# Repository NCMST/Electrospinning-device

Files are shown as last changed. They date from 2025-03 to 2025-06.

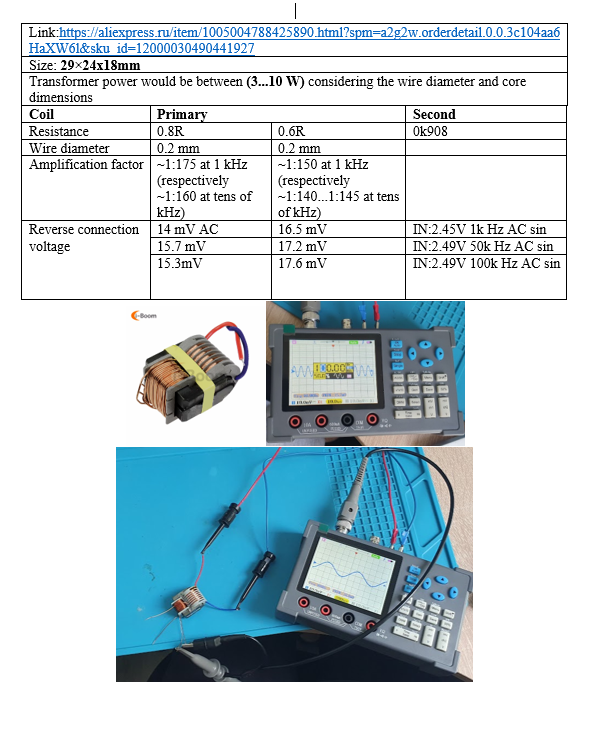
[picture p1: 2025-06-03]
Images/Transformer value.png

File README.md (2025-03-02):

<h2>Contents</h2>

<ul>
  <li><a href="#features">Features</a></li>
  <li><a href="#hardware-setup">Hardware Setup</a></li>
  <li><a href="#software-board-code">Software Board Code</a></li>
  <li><a href="#usage">Usage</a></li>
  <li><a href="#contributing">Contributing</a></li>
  <li><a href="#license">License</a></li>
</ul>

<h1>Electrospinning Device based on ATMEGA2560</h1>

<p>This repository contains the source code, hardware schematics, and documentation for a device designed to facilitate the electrospinning process using the ATMEGA2560 microcontroller (Arduino Mega).</p>

<h2 id="features">Features</h2>

<p>The device provides the following features:</p>
<ul>
  <li>Control and monitoring with BME280 sensor of temperature, pressure, humidity. And adjustable flow rate.</li>
  <li>FreeRTOS based task scheduler for easier and more efficient task management.</li>
  <li>High voltage source for electrospinning process.</li>
  <li>LCD display for monitoring.</li>
  <li>Motor for controlling the flow of the syringe. using driver TB6600.</li>
  <li>Encoder for user interaction.</li>
</ul>

<h2 id="hardware-setup">Hardware Setup</h2>

<table>
  <tr>
    <th>
      <p>The hardware setup consists of the following components:</p>
    </th>
  <tr>
    <td>
      <ul>
        <li><b>The high voltage power supply</b> generates the high voltage needed for the electrospinning process. It provides a stable and adjustable voltage source to create the electrostatic field required to draw the polymer solution into nanofibers.</li>
        <li><b>Varistor and Transformer</b> convert the high voltage to the voltage required for electrospinning.</li>
        <li><b>Multiplier/Rectifier</b> converts the voltage to the voltage required for the motor.</li>
      </ul>
    </td>
  </tr>
  <tr>
    <td>
      <h3>Comand Board</h3>
        <ul>
        <li><b>MCU</b> ATMEGA2560 (Mega 2560)</li>
        <li><b>Encoder</b> For seting the flow rate, starting and stopping the motor, and opening screen with sensor values.</li>
        <li><b>LCD Display</b> Show sensor values.</li>
        <li><b>TB6600</b> Stepper motor driver.</li>
        <li><b>Motor</b> Stepper motor for controlling the flow of the syringe.</li>
        <li><b>BME280</b> Sensor for monitoring temperature, pressure, and humidity.</li>
        <li><b>Power Supply</b> MCU power supply.</li>
      </ul>
    </td>
  </tr>
</table>
<ul>
  <li>See more about <a href="/Hardware/README.md">hardware Setup</a></li>
</ul>

<h2 id="software-board-code">Software Board Code</h2>
<ul>
  <li>See more about <a href="/Software/Source_code">software board code.</a></li>
  <!-- Builded file is ... -->
  <li>Get hex, elf files: <a href="/Software/Source_code/build/">software bulded code.</a></li>
</ul>

<h2>Usage</h2>

<p>To use the electrospinning device:</p>
<ol>
  <li>Connect the high voltage source to 220V.</li>
  <li>Connect the Arduino Mega to the components and upload the provided source code.</li>
  <li>Use the LCD screen with encoder to control and monitor the electrospinning process.</li>
  <li>Adjust the settings as needed and start the electrospinning process.</li>
  <li>Monitor the output and make adjustments as necessary.</li>
</ol>

<h2>Contributing</h2>
<p>Contributions to this project are welcome. Please fork the repository, make your changes, and submit a pull request.</p>

<h2>License</h2>
<p>This project is licensed under the <a href="LICENSE">MIT License</a>.</p>

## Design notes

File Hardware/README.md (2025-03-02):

# Electrospinning Device based on Arduino Mega

## High voltage result and schematics

### Reult

<p> The result of the electrospinning process is accesible on link below. </p>
<a href="https://docs.google.com/spreadsheets/d/1FEkuDaI_2rEFF1M06S9z06Yd7cQ-smT4pYeCvJsIN_U/edit?usp=sharing">Value on testing process</a>

### Schematics

## Hardware Connection

<h3>Display LCD I2C 16x2</h3>
<table style="border: none;">
  <tr>
    <th>Arduino Pins</th>
    <th>LCD Pin</th>
  </tr>
  <tr>
    <td>20</td>
    <td>21</td>
  </tr>
  <tr>
    <td>SCL</td>
    <td>SDA</td>
  </tr>
</table>

<h3>Motor</h3>
<table style="border: none;">
  <tr>
    <th>Arduino Pins</th>
    <th>Driver TB6600</th>
    <th>Motor Pin</th>
  </tr>
  <tr>
    <td>48</td>
    <td>ENA</td>
    <td>Enable Motor</td>
  </tr>
  <tr>
    <td>46</td>
    <td>DIR</td>
    <td>Direction Motor</td>
  </tr>
  <tr>
    <td>44</td>
    <td>PUL</td>
    <td>Pulse Motor</td>
  </tr>

  <h3>Encoder</h3>
  <table style="border: none;">
  <tr>
    <th>Arduino Pins</th>
    <th>Driver TB6600</th>
    <th>Encoder Pin</th>
  </tr>
  <tr>
    <td>26</td>
    <td>CLK</td>
    <td>Encoder Clock</td>
  </tr>
  <tr>
    <td>24</td>
    <td>DT</td>
    <td>Encoder Data transfer</td>
  </tr>
  <tr>
    <td>22</td>
    <td>SW</td>
    <td>Encoder Switch select</td>
  </tr>
  </table>

<h3>ADC</h3>
<table style="border: none;">
  <tr>
    <th>Arduino Pins</th>
    <th>ADC Pin</th>
  </tr>
  <tr>
    <td>A9</td>
    <td>ADC</td>
  </tr>
</table>

<h3>PWM</h3>
<table style="border: none;">
  <tr>
    <th>Arduino Pins</th>
    <th>PWM Pin</th>
  </tr>
  <tr>
    <td>9</td>
    <td>PWM</td>
  </tr>
</table>

<h3>Relay</h3>
<table style="border: none;">
  <tr>
    <th>Arduino Pins</th>
    <th>Relay Pin</th>
  </tr>
  <tr>
    <td>15</td>
    <td>Relay</td>
  </tr>
</table>

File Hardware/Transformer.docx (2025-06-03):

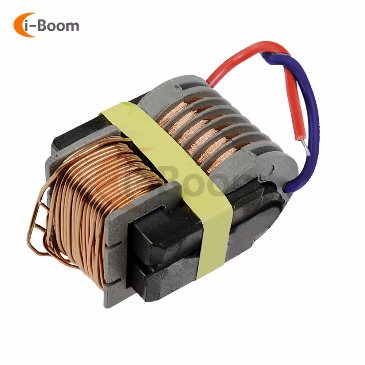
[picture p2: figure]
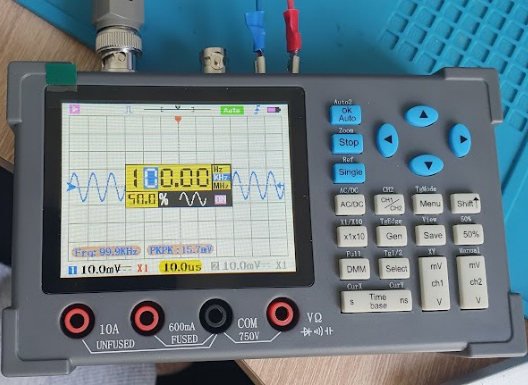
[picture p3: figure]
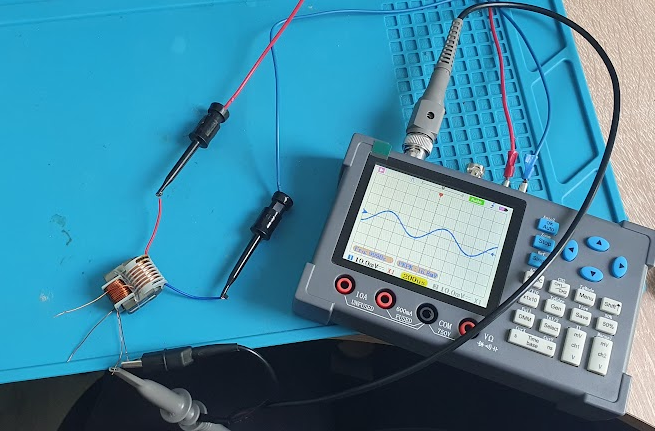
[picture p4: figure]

Link:https://aliexpress.ru/item/1005004788425890.html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

Size: 29×24x18mm

Transformer power would be between (3...10 W) considering the wire diameter and core dimensions
Coil | Primary | | Second
Resistance | 0.8R | 0.6R | 0k908
Wire diameter | 0.2 mm | 0.2 mm
Amplification factor | ~1:175 at 1 kHz (respectively ~1:160 at tens of kHz) | ~1:150 at 1 kHz (respectively ~1:140...1:145 at tens of kHz)
Reverse connection voltage | 14 mV AC | 16.5 mV | IN:2.45V 1k Hz AC sin
| 15.7 mV | 17.2 mV | IN:2.49V 50k Hz AC sin
| 15.3mV | 17.6 mV | IN:2.49V 100k Hz AC sin

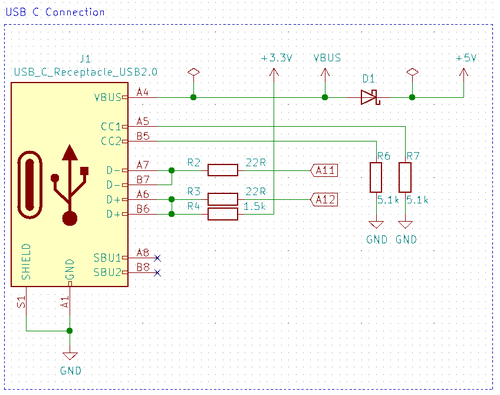
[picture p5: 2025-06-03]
Images/STM32 USB_Circuit_w._1.5_kOhm_pull-up.png

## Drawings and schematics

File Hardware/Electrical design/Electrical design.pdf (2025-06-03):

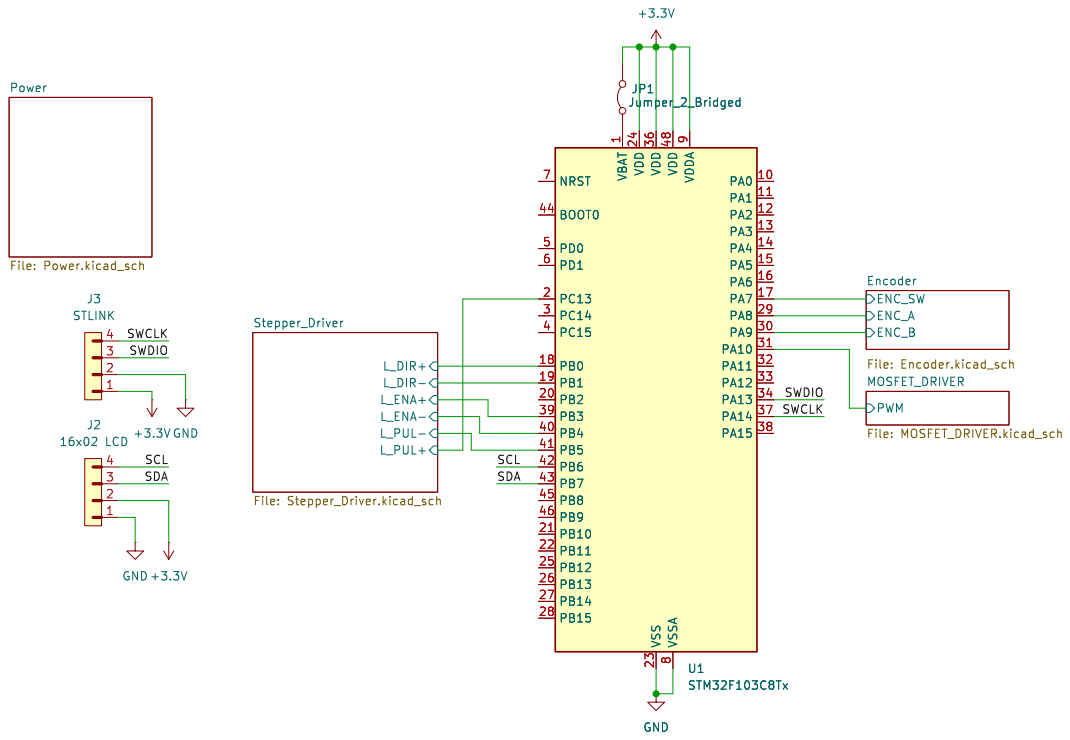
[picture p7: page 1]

File: MOSFET_DRIVER.kicad_sch Power File: Power.kicad_sch

1 VDD 24 VDD 36 VSS 23 VDD 48 VSSA

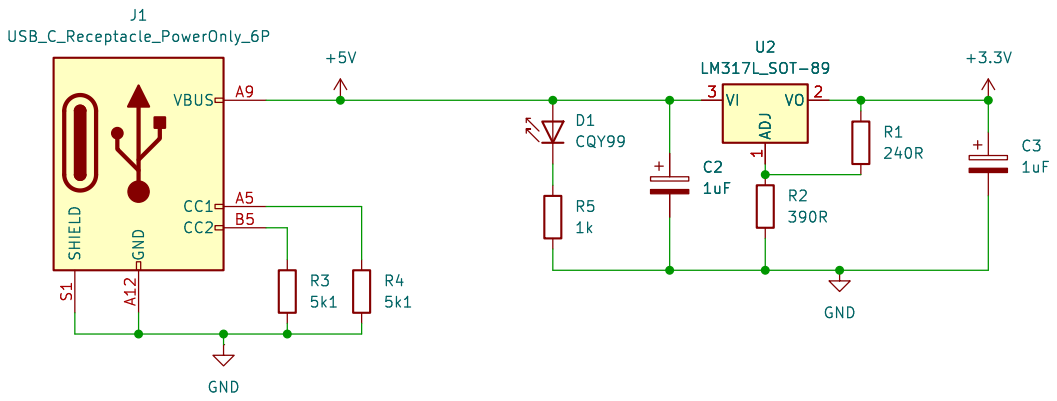
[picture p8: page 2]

Id: 2/5 Title: Power File: untitled.kicad_sch Sheet: /Power/R2

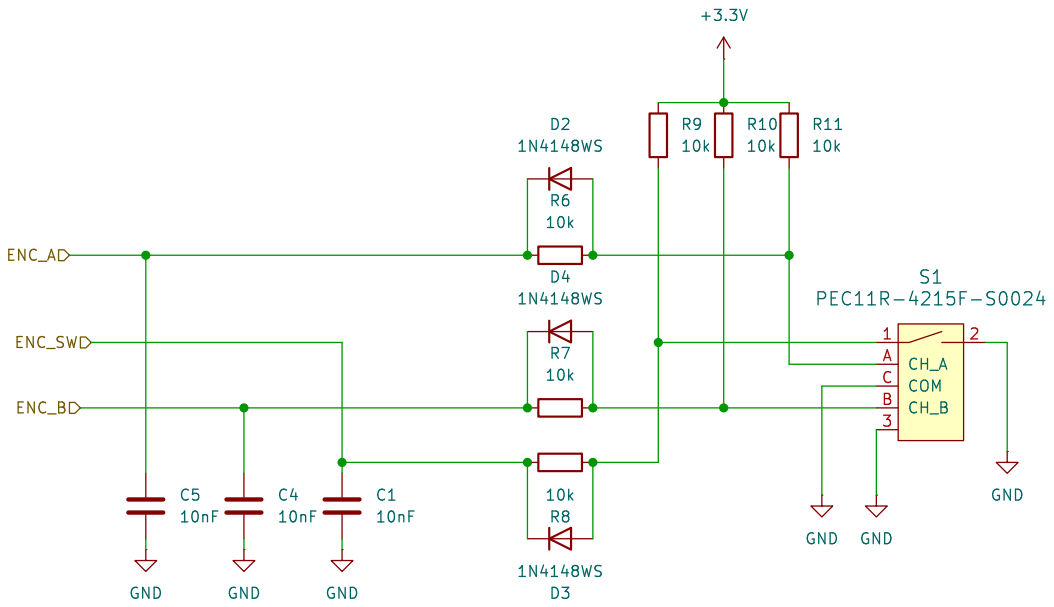
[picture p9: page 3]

Id: 3/5 Title: Power File: Encoder.kicad_sch Sheet: /Encoder/ GND

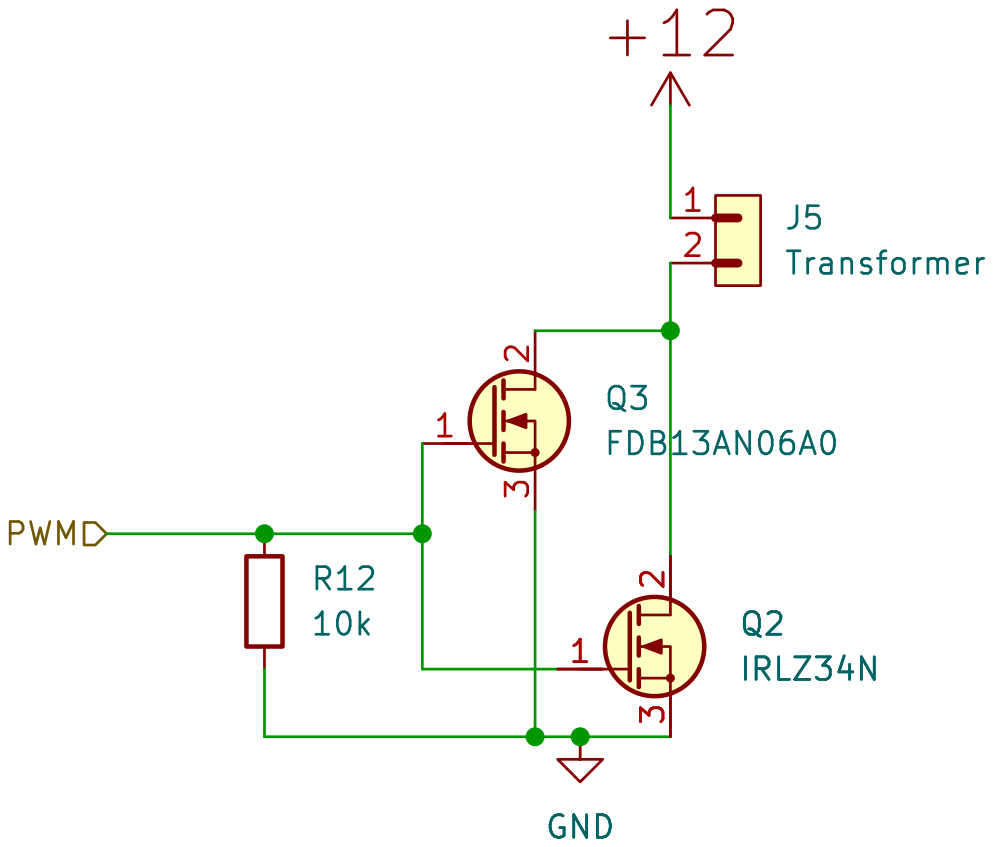
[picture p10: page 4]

Id: 4/5 Title: Power File: MOSFET_DRIVER.kicad_sch Sheet: /MOSFET_DRIVER/

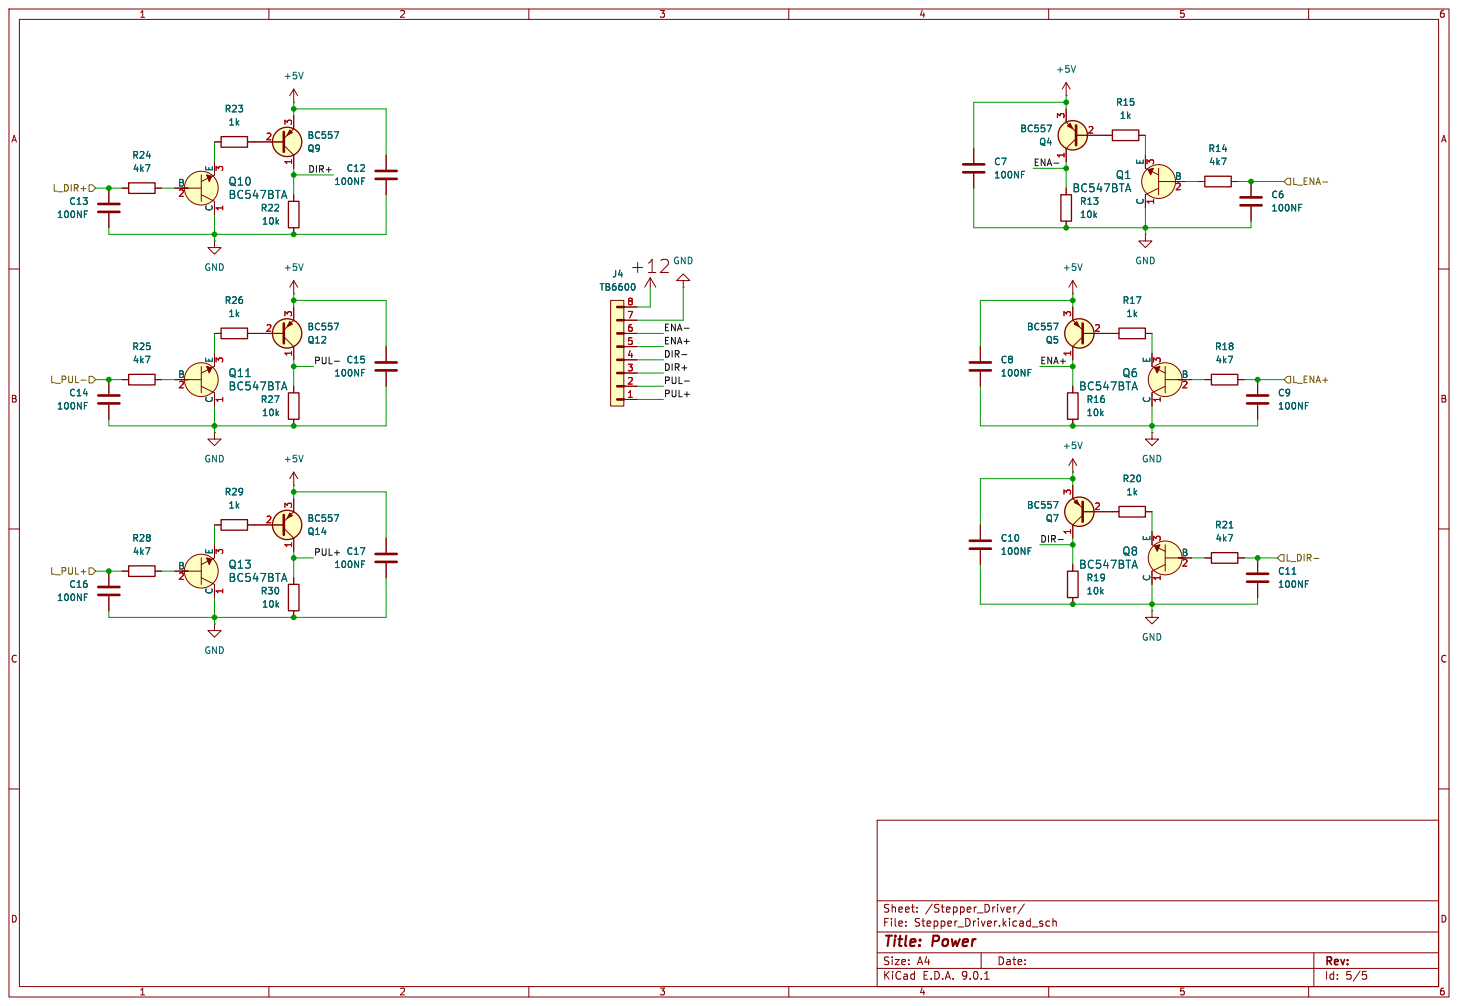
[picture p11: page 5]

Id: 5/5 Title: Power File: Stepper_Driver.kicad_sch Sheet: /Stepper_Driver/

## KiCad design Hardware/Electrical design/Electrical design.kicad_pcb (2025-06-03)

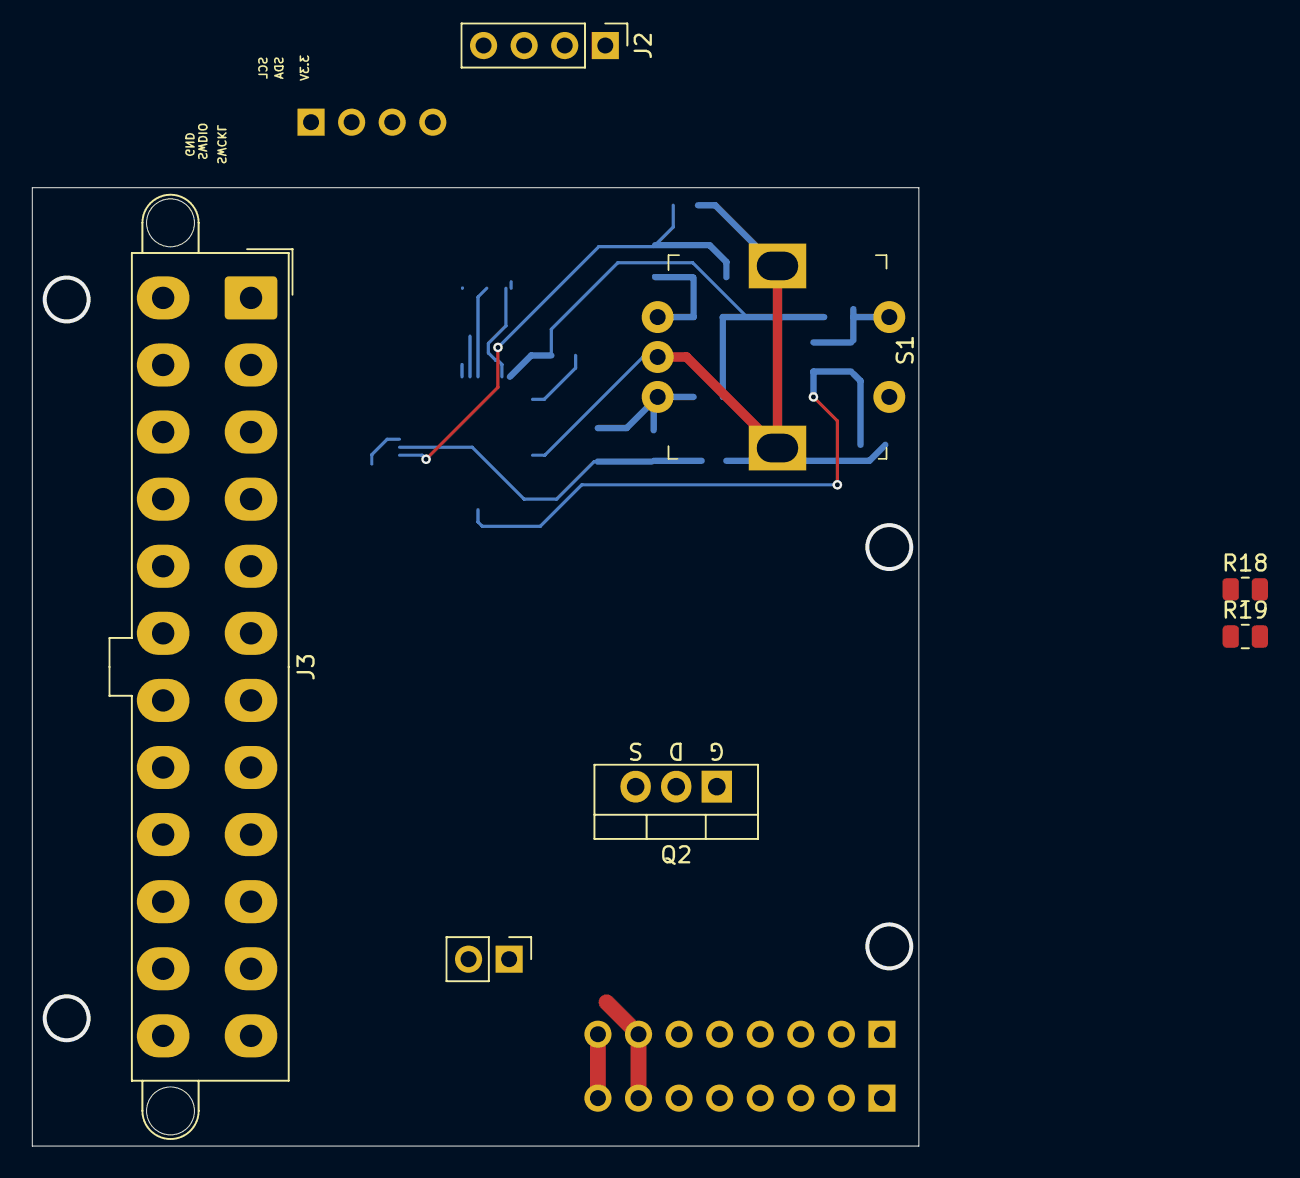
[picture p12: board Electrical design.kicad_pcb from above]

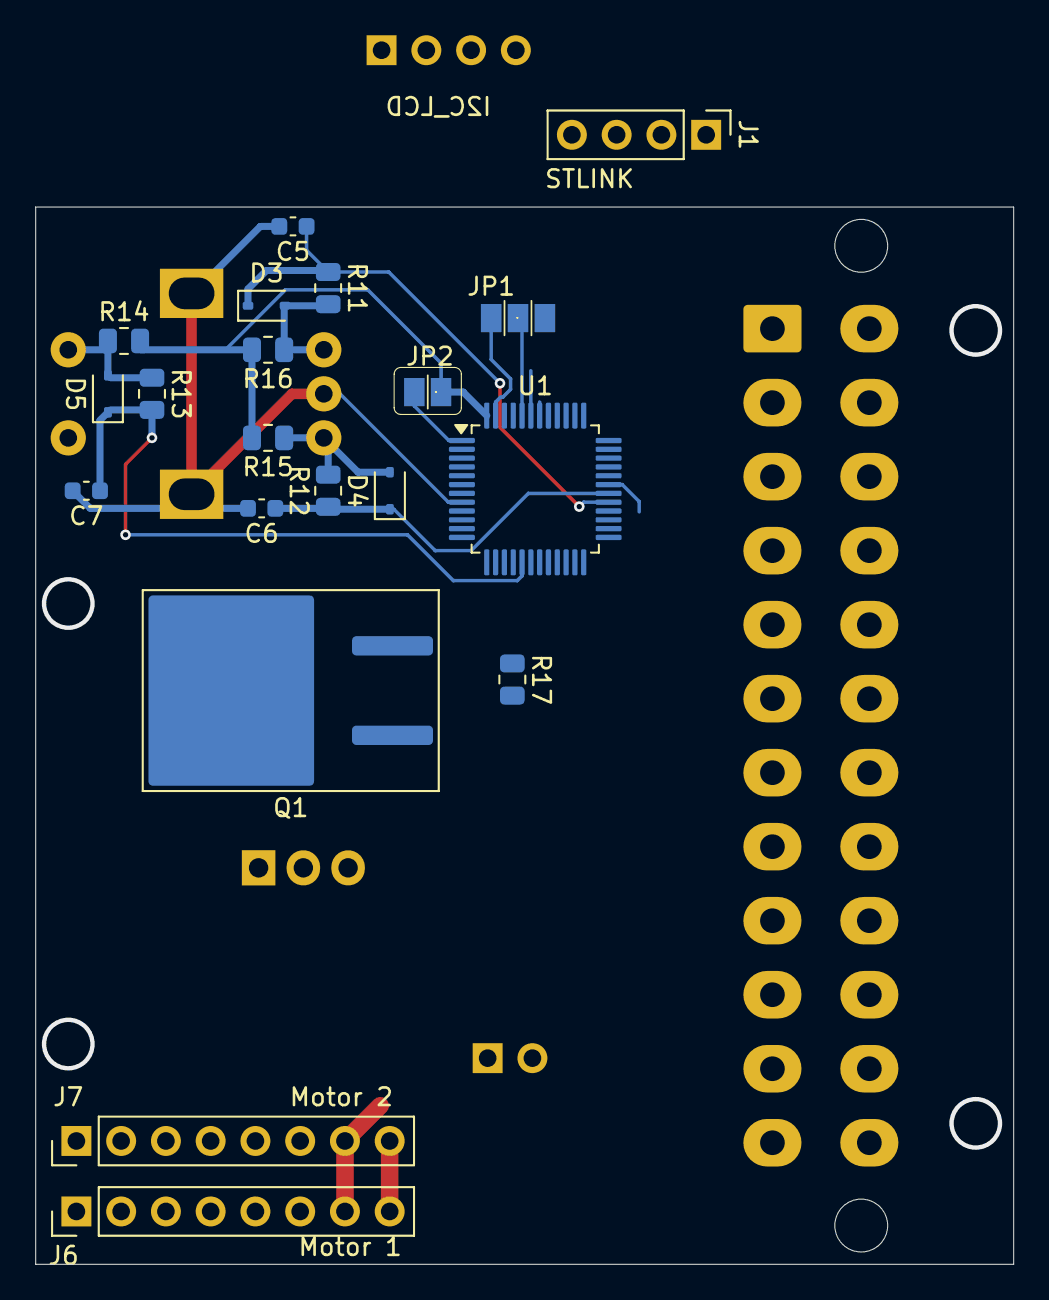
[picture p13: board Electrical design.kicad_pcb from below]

Board: 2 copper layers, 55.5 x 60.0 mm, 27 parts (20 on the bottom side), 21 nets.

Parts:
C5, C6, C7: 10nF; C_0603_1608Metric
D3, D4, D5: 1N4148WS; D_SOD-323
J1: STLINK; PinHeader_1x04_P2.54mm_Vertical
J2: LCD; PinHeader_1x04_P2.54mm_Vertical
J3: ATX-24; Molex_Mini-Fit_Jr_5566-24A2_2x12_P4.20mm_Vertical
J5: Transformer; PinHeader_1x02_P2.54mm_Vertical
J6: Motor 1; PinHeader_1x08_P2.54mm_Vertical
J7: Motor 2; PinHeader_1x08_P2.54mm_Vertical
JP1: BOOT; JUMPER_SMD_1x3
JP2: VBAT; JUMPER_SMD_1x2
Q1: FDB13AN06A0; TO-263-2
Q2: IRLZ34N; TO-220-3_Vertical_GDS
R11, R12, R13, R14, R15, R16, R17: 10k; R_0805_2012Metric
R18, R19: 1k; R_0805_2012Metric
S1: PEC11R-4215F-S0024; Rotary_Encoder_Switched_PEC11R
U1: STM32F103C8Tx; LQFP-48_7x7mm_P0.5mm

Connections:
+3.3V: J1.1, J2.2, J3.1 (+3.3V), J3.2 (+3.3V), J3.12 (+3.3V), J3.13 (+3.3V), JP1.3 (B), JP2.2 (B), R14.2, R15.2, R16.2, U1.9 (VDDA), U1.24 (VDD), U1.36 (VDD), U1.48 (VDD)
+5V: J3.4 (+5V), J3.6 (+5V), J3.21 (+5V), J3.22 (+5V), J3.23 (+5V)
+12V: J3.10 (+12V), J3.11 (+12V), J5.1
/Encoder/ENC_A: C5.1, D3.1 (K), R11.1, U1.29 (PA8)
/Encoder/ENC_B: C6.1, D4.1 (K), R12.1, U1.30 (PA9)
/Encoder/ENC_SW: C7.1, D5.1 (K), R13.2, U1.17 (PA7)
/MOSFET_DRIVER/PWM: Q1.1 (G), Q2.1 (G), R17.2, U1.31 (PA10)
/Power/PWR_OK: R18.1, R19.2
/SCL: J2.4, U1.42 (PB6)
/SDA: J2.3, U1.43 (PB7)
/SWCLK: J1.4, U1.37 (PA14)
/SWDIO: J1.3, U1.34 (PA13)
GND: C5.2, C6.2, C7.2, J1.2, J2.1, J3.3 (GND), J3.5 (GND), J3.7 (GND), J3.15 (GND), J3.16 (PS_ON#), J3.17 (GND), J3.18 (GND), J3.19 (GND), J3.24 (GND), J6.7, J7.7, JP1.1 (A), Q1.3 (S), Q2.3 (S), R17.1, R19.1, S1.2, S1.3, S1.C (COM), U1.8 (VSSA), U1.23 (VSS), U1.35 (VSS), U1.47 (VSS)
unnamed: D3.2 (A), R11.2, R16.1, S1.A (CH_A)
unnamed: D4.2 (A), R12.2, R15.1, S1.B (CH_B)
unnamed: D5.2 (A), R13.1, R14.1, S1.1
unnamed: J3.8 (PWR_OK), R18.2
unnamed: JP1.2 (C), U1.44 (BOOT0)
unnamed: JP2.1 (A), U1.1 (VBAT)
unnamed: J5.2, Q1.2 (D), Q2.2 (D)
P,+12: J6.8, J7.8

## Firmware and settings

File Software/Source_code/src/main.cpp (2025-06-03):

/**
 * @file main.cpp
 * @author Creciunel Catalin
 * @brief entry point of the program
 * @version 0.1
 * @date 2025-03-02
 *
 * @copyright Copyright (c) 2025
 *
 */
#include "main.h"

/**
 * @brief Declare the tasks
 *  - vTaskEncoder - Task for the encoder
 *  - vTaskMotor - Task for the motor
 *  - vTaskLCD - Task for the LCD
 *  - vTaskCommunication - Task for the communication
 *  - vTaskSensor - Task for the sensor
 *
 * @param pvParameters
 */
void vTaskEncoder(void *pvParameters);
void vTaskMotor(void *pvParameters);
void vTaskLCD(void *pvParameters);
void vTaskCommunication(void *pvParameters);
void vTaskSensor(void *pvParameters);

/**
 * @brief Motor variables
 * - motor1Speed - Speed of the first motor (float to allow fractional values)
 * - motor2Speed - Speed of the second motor (uint8_t)
 * - motorDirection - Direction of the motor (LOW - Forward, HIGH - Backward)
 */
float motor1Speed = 0.1;
uint8_t motor2Speed = 25;
uint8_t motorDirection = LOW;

/**
 * @brief Global variables for
 * - PWM value for the transformer
 * - Voltage value
 * - Temperature value
 * - Humidity value
 * - Pressure value
 *
 */
float pwmDutyCycle = 0.5;
uint8_t pwmFreq = 39;
float voltage = 0.0;
float temperature = 0.0;
float humidity = 0.0;
float pressure = 0.0;

/**
 * @brief Define the global object for the encoder
 *
 * @return Encoder
 */
Encoder enc(CLK, DT, SW, TYPE1);
/**
 * @brief Define the gobal LCD object
 *
 */
LiquidCrystal_I2C lcd(ADDRESS, DISPLAY_WIDTH, DISPLAY_HEIGHT);

/**
 * @brief Define the global object for the stepper motor driver
 *
 */
MWCSTEPPER tb6600_m1(ENA_PIN1, DIR_PIN1, PUL_PIN1);

/**
 * @brief Define the global object for the stepper motor driver
 *
 */
AF_DCMotor motor(1);

/**
 * @brief Define the global flag for the start/stop state
 *  - start - Start/Stop state
 *
 */
struct Flag
{
    uint8_t start = 0;
} flag;

/**
 * @brief Setup function
 * - Initialize the serial communication
 * - Enable the watchdog timer
 * - Create the tasks
 * - Start the FreeRTOS scheduler
 * - Initialize the PWM for the transformer
 * - Initialize the LCD
 * - Set the motor speed
 *
 */
void setup()
{
    Serial.begin(115200);

    wdt_enable(WDTO_2S);

    xTaskCreate(vTaskEncoder, "Encoder Task", 512, NULL, 1, NULL);
    xTaskCreate(vTaskMotor, "Motor Task", 512, NULL, 1, NULL);
    xTaskCreate(vTaskLCD, "LCD Task", 256, NULL, 1, NULL);
    xTaskCreate(vTaskCommunication, "Communication Task", 128, NULL, 1, NULL);
    xTaskCreate(vTaskSensor, "Sensor Task", 256, NULL, 1, NULL);

    vTaskStartScheduler();

    lcd.init();
    lcd.backlight();

    motor.setSpeed(motor2Speed);
    motor.run(RELEASE);
}

/**
 * @brief Loop function
 * is not used in FreeRTOS
 */
void loop() {}

/**
 * @brief Task for the LCD
 * - Displays the current state of the system
 * - Displays the current speed of the motor
 * - Displays the current direction of the motor
 * - Displays the current sensor values
 * - Displays the current PWM duty cycle
 * - Updates the LCD every 500 ms
 * - Reset the watchdog timer
 *
 * @param pvParameters
 */
void vTaskLCD(void *pvParameters)
{

    lcd.init();
    lcd.backlight();

    for (;;)
    {
        wdt_reset();

        lcd.clear();

        switch (currentState)
        {
        case MAIN_MENU:
            lcd.setCursor(0, 0);
            lcd.print("Electrospinning");
            lcd.setCursor(11, 1);
            lcd.print("setup");
            break;

        case SELECT_DIRECTION:
            lcd.setCursor(0, 0);
            lcd.print("Direction:");
            lcd.setCursor(0, 1);
            lcd.print(motorDirection == LOW ? "Forward" : "Backward");
            break;

        case SELECT_MOTOR1_SPEED:
            lcd.setCursor(0, 0);
            lcd.print("Motor 1 speed:");
            lcd.setCursor(0, 1);
            lcd.print(String(motor1Speed, 2)); // Show the current speed with two decimals
            break;

        case SELECT_MOTOR2_SPEED:
            lcd.setCursor(0, 0);
            lcd.print("Motor 2 speed:");
            lcd.setCursor(0, 1);
            lcd.print(int(motor2Speed)); // Show the current speed
            break;

        case SENSOR_VALUES:
            lcd.setCursor(0, 0);
            lcd.print("V_out:" + String(int(voltageValue(analogRead(ADC_PIN)) / 1000.0)) + "kV");
            lcd.setCursor(0, 1);
            lcd.print("T:" + String((int)(temperature)));
            lcd.setCursor(5, 1);
            lcd.print("H:" + String((int)(humidity)));
            lcd.setCursor(10, 1);
            lcd.print("P:" + String((int)(pressure)));
            lcd.setCursor(11, 0);
            lcd.print(flag.start ? "Start" : "Stop");
            break;
        case TRAN_PWM_DUTY:
            lcd.setCursor(0, 0);
            lcd.print("PWM Duty:");
            lcd.setCursor(0, 1);
            lcd.print(pwmDutyCycle);
            break;
        case TRAN_PWM_FREQ:
            lcd.setCursor(0, 0);
            lcd.print("PWM Freq:");
            lcd.setCursor(10, 0);
            lcd.print(String(int((16000000.0 / (8 * (OCR2A + 1))/1000) * 10) / 10.0, 1) + "kHz"); // Show the current frequency with one decimal place
            lcd.setCursor(0, 1);
            lcd.print("OCR2A:");
            int fill = (int)(100.0 * OCR2B / OCR2A);
            lcd.setCursor(6, 1);
            lcd.print(String(fill) + "%");
            break;
        }

        vTaskDelay(TASK_DELAY_LCD / portTICK_PERIOD_MS); // Update the LCD every 500 ms
    }
}

/**
 * @brief Task for the motor
 * - Initialize the motor driver
 * - Set the motor direction
 * - Set the motor speed
 * - Start the motor
 * - Stop the motor
 * - Reset the watchdog timer
 *
 * @param pvParameters
 */
void vTaskMotor(void *pvParameters)
{
    tb6600_m1.init();
    pinMode(RELAY_PIM, OUTPUT);

    pinMode(PWM_PIN, OUTPUT);

    // Configurare Timer2 pentru Fast PWM pe pinul 9 (OC2B)
    TCCR2A = _BV(COM2B1) | _BV(WGM21) | _BV(WGM20); // Fast PWM, Non-inverting
    TCCR2B = _BV(WGM22) | _BV(CS21);                // Fast PWM cu prescaler = 8

    OCR2A = pwmFreq; // Aproximativ 50 kHz

    OCR2B = (int)(pwmDutyCycle * OCR2A); // Set the PWM duty cycle 50%

    for (;;)
    {
        // motor2Speed = map(motor2Speed, 0, 200, 0, 255);

        tb6600_m1.set(motorDirection == HIGH ? CLOCKWISE : COUNTERCLOCKWISE, motor1Speed, THIRTYTWO_STEP);
        if (flag.start)
        {
            digitalWrite(RELAY_PIM, HIGH);

            tb6600_m1.run(); // Start motorul
            motor.setSpeed(motor2Speed);
            motor.run(motorDirection == HIGH ? FORWARD : BACKWARD);
        }
        else
        {
            digitalWrite(RELAY_PIM, LOW);

            tb6600_m1.active(false); // Stop motorul
            motor.run(RELEASE);
        }
        wdt_reset(); // Resetare watchdog

        vTaskDelay(TASK_DELAY_MOTOR / portTICK_PERIOD_MS); // Delay for fast response
    }
}

/**
 * @brief Task for the encoder
 * - Change the menu state on press
 * - Reset to the initial state on double press
 * - Change the motor direction
 * - Change the motor speed
 * - Change the PWM duty cycle
 * - Reset the watchdog timer
 *
 * @param pvParameters
 */
void vTaskEncoder(void *pvParameters)
{
    for (;;)
    {
        enc.tick();

        if (enc.isSingle())
        {
            switch (currentState)
            {
            case MAIN_MENU:
                currentState = SELECT_DIRECTION;
                Serial.println("Select Direction");
                break;
            case SELECT_DIRECTION:
                currentState = SELECT_MOTOR1_SPEED;
                Serial.println("Select motor 1 speed");
                break;
            case SELECT_MOTOR1_SPEED:
                currentState = SELECT_MOTOR2_SPEED;
                Serial.println("Select motor 2 speed");
                break;
            case SELECT_MOTOR2_SPEED:
                currentState = TRAN_PWM_DUTY;
                Serial.println("PWM Duty");
                break;
            case TRAN_PWM_DUTY:
                currentState = TRAN_PWM_FREQ;
                Serial.println("PWM Frequency");
                break;
            case TRAN_PWM_FREQ: 
                currentState = MAIN_MENU;
                Serial.println("Back to Main Menu");
                break;
            case SENSOR_VALUES:
                currentState = MAIN_MENU;
                Serial.println("Back to Main Menu");
                break;
            }
        }

        else if (enc.isDouble())
        {
            currentState = SENSOR_VALUES;
            Serial.println("Sensor Values");

            if (flag.start)
            {
                flag.start = false;
                Serial.println("Stop");
                digitalWrite(EN_HIGH_VOLTAGE, LOW);
            }
            else
            {
                flag.start = true;
                Serial.println("Start");
                digitalWrite(EN_HIGH_VOLTAGE, HIGH);
            }
        }

        switch (currentState)
        {
        case SELECT_DIRECTION:
            if (enc.isRight())
            {
                motorDirection = LOW;
                Serial.println("Direction: Forward");
            }
            else if (enc.isLeft())
            {
                motorDirection = HIGH;
                Serial.println("Direction: Backward");
            }
            break;
        case SELECT_MOTOR1_SPEED:
            if (enc.isLeft())
            {
                if (motor1Speed >= 1)
                {
                    motor1Speed++;
                    motor1Speed > 100 ? motor1Speed = 100 : motor1Speed = motor1Speed;
                }
                else if (motor1Speed >= 0.1 && motor1Speed < 1)
                {
                    motor1Speed += 0.1;
                }

                Serial.println("Speed: " + String(motor1Speed, 2));
            }
            else if (enc.isRight())
            {
                if (motor1Speed >= 1)
                {
                    motor1Speed--;
                    Serial.println("Speed: " + String(motor1Speed, 2));
                }
                else if (motor1Speed < 1 && motor1Speed >= 0.1)
                {
                    motor1Speed -= 0.1;
                    if (motor1Speed < 0.1)
                        motor1Speed = 0.1;

                    Serial.println("Speed: " + String(motor1Speed, 2));
                }
            }
            break;
        case SELECT_MOTOR2_SPEED:
            if (enc.isLeft())
            {
                motor2Speed++;
                motor2Speed > 200 ? motor2Speed = 200 : motor2Speed = motor2Speed;
                Serial.println("Speed: " + String(motor2Speed));
            }
            else if (enc.isRight())
            {
                motor2Speed--;
                motor2Speed < 1 ? motor2Speed = 1 : motor2Speed = motor2Speed;
                Serial.println("Speed: " + String(motor2Speed));
            }
            break;
        case TRAN_PWM_DUTY:
            if (enc.isLeft())
            {
                pwmDutyCycle += 0.1;
                pwmDutyCycle > 1 ? pwmDutyCycle = 1 : pwmDutyCycle = pwmDutyCycle;

                Serial.println("PWM Duty: " + String(pwmDutyCycle));
            }
            else if (enc.isRight())
            {
                pwmDutyCycle -= 0.1;
                pwmDutyCycle < 0 ? pwmDutyCycle = 0 : pwmDutyCycle = pwmDutyCycle;
                Serial.println("PWM Duty: " + String(pwmDutyCycle));
            }
            OCR2B = (int)(pwmDutyCycle * OCR2A); // Set the PWM duty cycle 50%
            break;
        case TRAN_PWM_FREQ:
            if (enc.isLeft())
            {
                OCR2A++;
                OCR2A > 255 ? OCR2A = 255 : OCR2A = OCR2A;
                Serial.println("OCR2A: " + String(OCR2A));
            }
            else if (enc.isRight())
            {
                OCR2A--;
                OCR2A < 0 ? OCR2A = 0 : OCR2A = OCR2A;
                Serial.println("OCR2A: " + String(OCR2A));
            }
        case SENSOR_VALUES:
            break;
        case MAIN_MENU:
            break;
        }

        wdt_reset();

        vTaskDelay(TASK_DELAY_ENCODER / portTICK_PERIOD_MS);
    }
}

/**
 * @brief Communication task
 * - Read commands from the serial port
 * - Initialize variables based on commands
 *
 * - s - start, d - direction, D- duty cycle, m - motor 1 speed, M - motor 2 speed
 * Vlues: s - 0/1, d - 0/1, D - 0-1 (float), m - 0-100, M - 1-200
 *
 * @param pvParameters
 */
void vTaskCommunication(void *pvParameters)
{
    Serial.println("System Initialized\r\n s - start, d - direction, D- duty cycle, F - PWM frequency, m - motor 1 speed, M - motor 2 speed\r\n");

    for (;;)
    {
        if (Serial.available() > 0)
        {
            char key = Serial.read();
            // int val = Serial.parseInt();
            float val = Serial.parseFloat();

            switch (key)
            {
            case 's':
                (int)val > 0 and (int) val < 1 ? flag.start = (int)val : Serial.println("Wrong value for start, val: " + String(val) + ", min: 0 - stop, max: 1 - start");
                flag.start = val;
                digitalWrite(ENA_PIN1, flag.start ? LOW : HIGH); // Enable/disable the driver
                digitalWrite(ENA_PIN2, flag.start ? LOW : HIGH);
                digitalWrite(EN_HIGH_VOLTAGE, flag.start ? HIGH : LOW);
                break;
            case 'd':
                (int)val > 0 and (int) val < 1 ? motorDirection = (int)val : Serial.println("Wrong value for motor direction, vauel: " + String(val) + ", min: 0 - clockwise, max: 1 - counterclockwise");
                break;
            case 'D':
                val > 0 and val < 1 ? pwmDutyCycle = val : Serial.println("Wrong value for pwm duty cycle, value: " + String(val) + ", min: 0 - 0%, max: 1 - 100%");
                OCR2B = (int)(pwmDutyCycle * OCR2A); // Set the PWM duty cycle 50%
                break;
            case 'F':
                (int)val > 0 and (int) val < 255 ? OCR2A = (int)val : Serial.println("Wrong value for PWM frequency, value: " + String(val) + ", min: 0 - 0%, max: 1 - 100%");
                break;
            case 'm':
                val > 0 and val < 100 ? motor1Speed = val : Serial.println("Wrong value for motor 1 speed, value: " + String(val) + ", min: 0 - 0%, max: 1 - 100%");
                break;
            case 'M':
                (int)val > 0 and (int) val < 200 ? motor2Speed = (int)val : Serial.println("Wrong value for motor 2 speed, value: " + String(val) + ", min: 0 - 0%, max: 1 - 100%");
                break;
            default:
                Serial.println("Wrong command! key: " + String(key) + ", value: " + String(val));
                break;
            }
        }

        wdt_reset();

        vTaskDelay(TASK_DELAY_COMMUNICATION / portTICK_PERIOD_MS);
    }
}

/**
 * @brief Sensor task
 * - Read temperature, humidity and pressure from the BME280 sensor
 *
 * Temperature - °C
 * Humidity - %
 * Pressure - hPa
 *
 * @param pvParameters
 */
void vTaskSensor(void *pvParameters)
{
    Adafruit_BME280 bme;

    if (!bme.begin(0x76))
    {
        Serial.println("Could not find a valid BME280 sensor, check wiring!");
        vTaskDelete(NULL);
    }

    for (;;)
    {

        temperature = bme.readTemperature();
        humidity = bme.readHumidity();
        pressure = bme.readPressure() / 100.0F; // Convert in  hPa

        wdt_reset();

        vTaskDelay(TASK_DELAY_SENSOR / portTICK_PERIOD_MS);
    }
}

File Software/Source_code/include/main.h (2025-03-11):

/**
 * @file main.h
 * @author Creciunel Catalin
 * @brief Definition and declaration of the main program
 * @version 0.1
 * @date 2025-03-02
 * 
 * @copyright Copyright (c) 2025
 * 
 */
#include <Wire.h>
#include <LiquidCrystal_I2C.h>
#include <Arduino.h>

#include <Arduino_FreeRTOS.h>

#include <Adafruit_Sensor.h>
#include <Adafruit_BME280.h>

#include <AFMotor.h>

#include <mwc_stepper.h>
#include <GyverEncoder.h>

#include <avr/wdt.h>

/**
 * @brief FreeRTOS tasks time constants 
 * - TASK_DELAY_MOTOR - Delay for the motor task
 * - TASK_DELAY_LCD - Delay for the LCD task
 * 
 */
#define TASK_DELAY_MOTOR 20
#define TASK_DELAY_LCD  500
#define TASK_DELAY_ENCODER 30
#define TASK_DELAY_COMMUNICATION 100
#define TASK_DELAY_SENSOR 2000


/**
 * @brief OLED display constants pins
 * - ADDRESS - I2C address
 * - SCL_PIN - SCL pin for the I2C communication
 * - SDA_PIN - SDA pin for the I2C communication
 * - DISPLAY_HEIGHT - Height of the display
 * - DISPLAY_WIDTH - Width of the display
 */
#define ADDRESS 0x27 // I2C address
#define SCL_PIN 21
#define SDA_PIN 20

#define DISPLAY_HEIGHT 2
#define DISPLAY_WIDTH 16

/**
 * @brief Constants for stepper driver (TB6600) pins Pump
 * - DIR_PIN1 - Direction pin for the first motor
 * - PUL_PIN1 - Pulse pin for the first motor
 * - ENA_PIN1 - Enable pin for the first motor
 */
#define DIR_PIN1 46 // DIR+
#define PUL_PIN1 44 // PUL+
#define ENA_PIN1 48 // ENA+

/**
 * @brief Constants for stepper driver (TB6600) pins Colector 
 * - DIR_PIN2 - Direction pin for the second motor
 * - PUL_PIN2 - Pulse pin for the second motor
 * - ENA_PIN2 - Enable pin for the second motor
 */
#define DIR_PIN2 47 
#define PUL_PIN2 45 
#define ENA_PIN2 49 

/**
 * @brief Stepper motor driver constants
 * - CLOCKWISE - Clockwise direction
 * - COUNTERCLOCKWISE - Counterclockwise direction
 * - FULL_STEP - Full step mode
 * - HALF_STEP - Half step mode
 * - QUARTER_STEP - Quarter step mode
 * - EIGHTH_STEP - Eighth step mode
 * - SIXTEENTH_STEP - Sixteenth step mode
 * - THIRTYTWO_STEP - Thirtytwo step mode
 */
#define CLOCKWISE 1
#define COUNTERCLOCKWISE 0

#define FULL_STEP 200
#define HALF_STEP 400
#define QUARTER_STEP 800
#define EIGHTH_STEP 1600
#define SIXTEENTH_STEP 3200
#define THIRTYTWO_STEP 6400

/**
 * @brief ADC constants
 * - ADC_PIN - Analog to digital conversion pin
 * - ADC_RESOLUTION - Resolution of the ADC
 * - R2 - Resistor value for the first voltage divider (R2 = 10k)
 * - R1 - Resistor value for the second voltage divider (R1 = 47k)
 * - R3 - Resistor value for the third voltage divider (R3 = 7.2k)
 * - R4 - Resistor value for the fourth voltage divider (R4 = 1.5k)
 * 
 */
#define ADC_PIN A9 
#define ADC_RESOLUTION 5.0 / 1024.0
#define R2 10151.5  
#define R1 48300000 
#define R3 7200     
#define R4 1500     

/**
 * @brief Macro to calculate the voltage gain
 * 
 */
#define VOLTAGE_GAIN ((R1 + R2) / R2)

/**
 * @brief Time constants
 * - PRINT_DELAY - Delay for printing the values on the serial monitor
 * - COMMUNICATION_DELAY - Delay for the communication task
 * - ENCODER_DELAY - Delay for the encoder task
 * 
 */
#define PRINT_DELAY 2000
#define COMMUNICATION_DELAY 100
#define ENCODER_DELAY 100

/**
 * @brief Macro to convert milliseconds to seconds
 * 
 */
#define MillisecondsToMinutes(milliseconds) ((milliseconds) / 60000.0)

/**
 * @brief Encoder pins
 *  - CLK - Encoder Clock pin
 *  - DT - Encoder Data transfer pin
 *  - SW - Encoder Switch select pin
 */
#define CLK 26
#define DT 24
#define SW 22

/**
 * @brief Relay pin for the high voltage control
 * 
 */
#define RELAY_PIM 15

#define PWM_PIN 9

/**
 * @brief Relay pin for the high voltage control
 * 
 */
#define EN_HIGH_VOLTAGE 13

/**
 * @brief State machine for the display menu
 * 
 * @enum MenuState - Elements of the state machine
 * @var MAIN_MENU - Logo for the display menu
 * @var SELECT_DIRECTION - Select the direction of the motor 1
 * @var SELECT_MOTOR1_SPEED - Select the sering pump speed
 * @var SELECT_MOTOR2_SPEED - Select the colector speed
 * @var SENSOR_VALUES - Display the generan values after starting as temperature, humidity, pressure, voltage, state: start/stop.
 * @var TRAN_PWM_DUTY - Display the PWM duty cycle for the transformer.
 */
enum MenuState
{
    MAIN_MENU, 
    SELECT_DIRECTION,
    SELECT_MOTOR1_SPEED,
    SELECT_MOTOR2_SPEED,
    SENSOR_VALUES,
    TRAN_PWM_DUTY,
    TRAN_PWM_FREQ
};

MenuState currentState = MAIN_MENU;

/**
 * @brief Read the high voltage value usind a high voltage probe from the ADC pin
 * 
 * @param adcValue 
 * @return int 
 */
int voltageValue(uint16_t adcValue)
{
    // Calculate Vout1 from the first divider
    float Vout1 = (ADC_RESOLUTION * adcValue) * ((R1 + R2) / R2);

    // Calculate Vout2 from the second divider
    float Vout2 = Vout1 * ((R3 + R4) / R4);

    return Vout2; // Return the final scaled voltage
}

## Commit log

2025-03-02 Add PWM duty option
2025-03-05 Add 50Hz PWM
2025-06-03 Update schematic
    [Electrical design.kicad_pcb, Electrical design.kicad_sch, Electrospining PCB.PrjPcb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]
